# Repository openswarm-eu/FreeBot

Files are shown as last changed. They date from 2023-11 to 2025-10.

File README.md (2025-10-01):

# FreeBot
Contains FreeBot files and source code.
The Hardware folder contains schematics for the various versions of the FreeBot board and associated evaluation boards.
The software folder contains the FreeBot subfolder, which contains the core functionality of FreeBot and reference implementation of the library for BLE control. 
The repository will keep being updated with designs for both hardware and software.

# Hardware revisions

| Version | SoC | Feather-header | Picture |
|:---:|:---:|:---:|:---:|
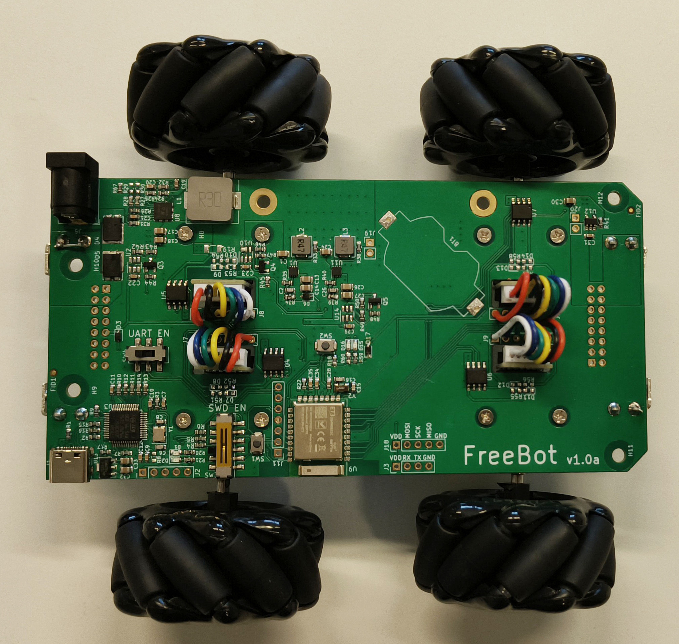
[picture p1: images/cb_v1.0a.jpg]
Picture of CapBot v1.0a
| [v1.0a](#v10a) | nrf52840 | &cross; ||
| [v1.1a](#v11a) | nrf52840 | &cross; |Picture of CapBot v1.1a|
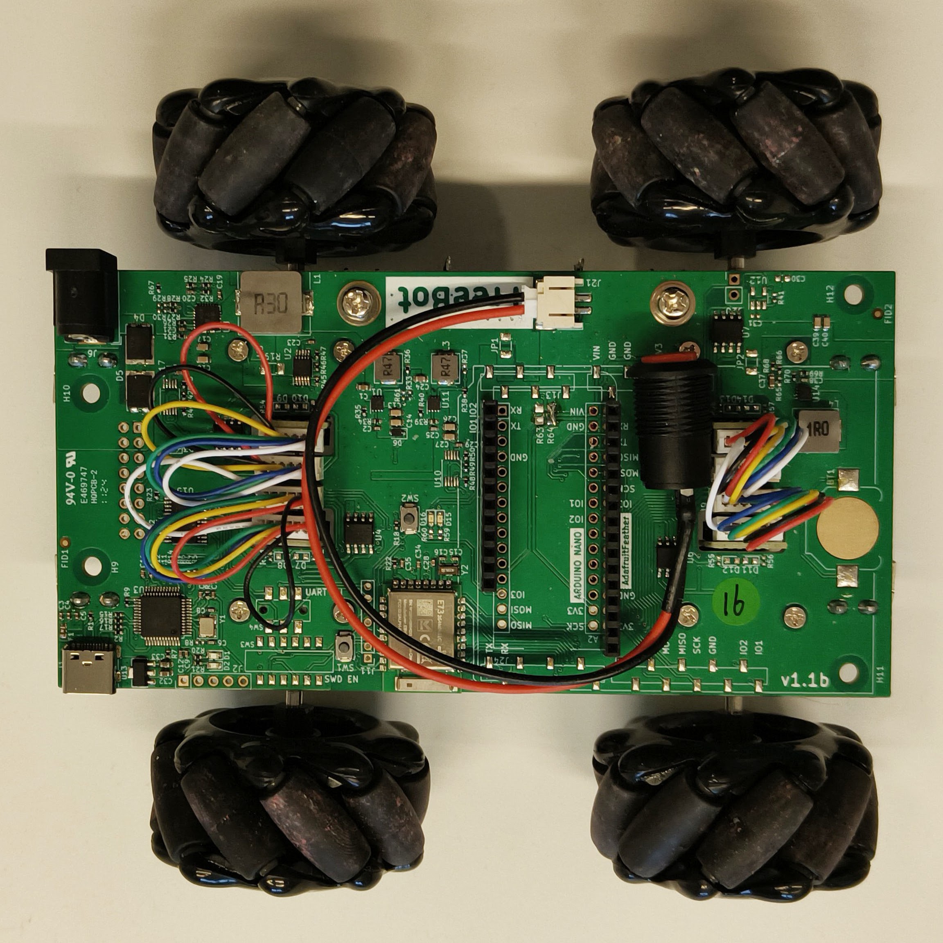
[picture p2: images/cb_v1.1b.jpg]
Picture of CapBot v1.1b
| [v1.1b](#v11b) | nrf52840 | &check; ||

## v1.0a

CapBot v1.0 has a physical switch (`SW4`) to cut the UART lines from the DAP-link on-board debugger.
This switch should be enabled when printing to a serial terminal over USB.

Furthermore, another physical switch (`SW3`) cuts the SWD lines used for programming the &micro;Processor.
This switch should be enabled in order to flash.

## v1.1a

Nothing special (yet).

## v1.1b

> [!WARNING]
> The pins `IO1`, `IO2` and `IO3` on the feather-header correspond with `D15`, `D16` and `SW2` respectively.
> Make sure that these are not shorted accidentally because of this.
> Schematic view

# Acknowledgement

Part of the source code in this repository is developed within the frame and for the purpose of the OpenSwarm project. This project has received funding from the European Unioan's Horizon Europe Framework Programme under Grant Agreement No. 101093046.

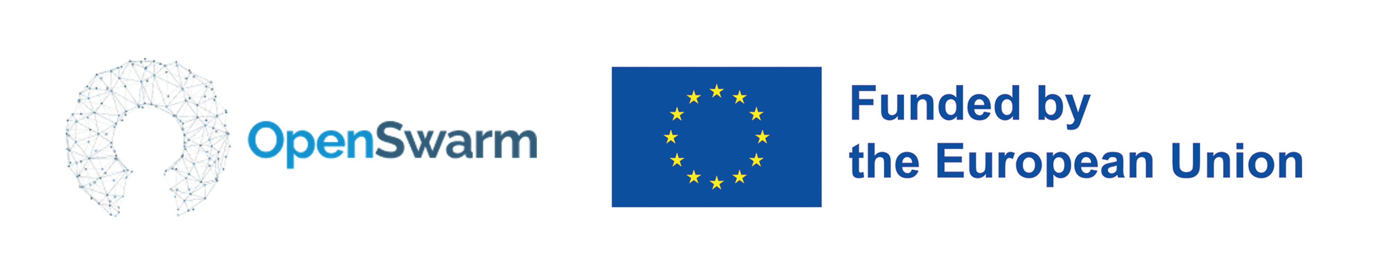
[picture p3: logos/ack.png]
OpenSwarm - Funded by the European Union


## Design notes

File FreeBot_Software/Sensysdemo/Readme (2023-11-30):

This version is based on the Adafruit nrf52840 express, and the code can be opened and used with an Arduino.

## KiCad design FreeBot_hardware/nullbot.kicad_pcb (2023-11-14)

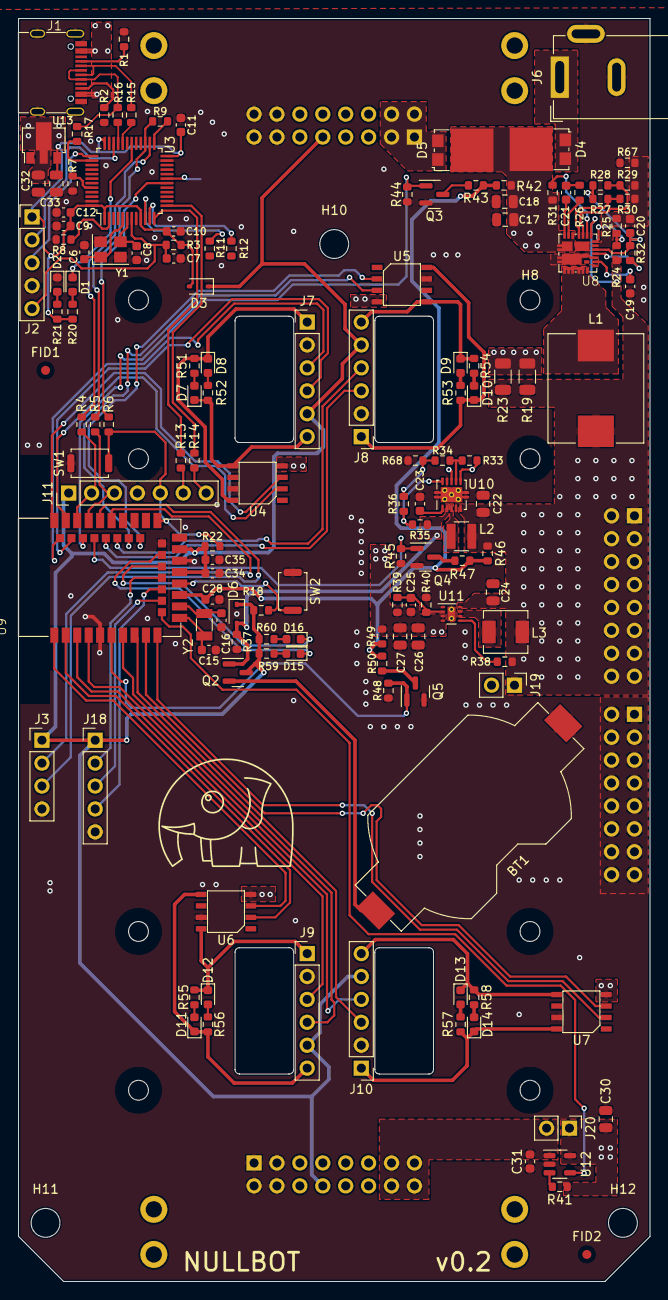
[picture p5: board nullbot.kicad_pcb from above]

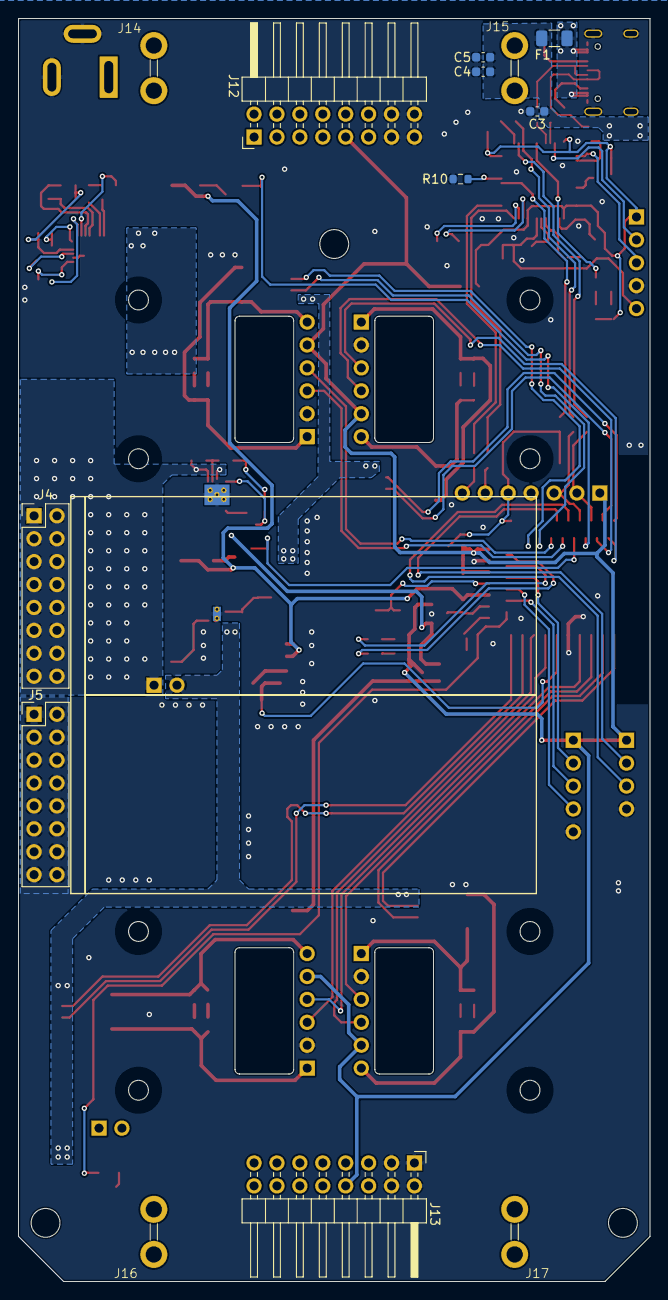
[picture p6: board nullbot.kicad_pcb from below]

Board: 2 copper layers, 70.0 x 140.0 mm, 165 parts (13 on the bottom side), 116 nets.

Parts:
BT1: Battery_Cell; BatteryHolder_Keystone_1058_1x2032
C3, C4, C5, C20: 1uF; C_0603_1608Metric
C6, C8: 22p; C_0603_1608Metric
C7, C9, C10, C11, C12: 100n; C_0603_1608Metric
C15, C16: 12pF; C_0603_1608Metric
C17, C18, C26, C27: 22uF; C_0805_2012Metric
C19: 2.2uF; C_0603_1608Metric
C21, C23, C31, C34, C35: 0.1uF; C_0603_1608Metric
C22, C24, C30, C32, C33: 10uF; C_0805_2012Metric
C25: 10pF; C_0603_1608Metric
C28: 0.01uF; C_0603_1608Metric
D1: Red; LED_0603_1608Metric
D2: Green; LED_0603_1608Metric
D3, D6: CUS10S30,H3F; D_SOD-323
D4, D5: 10S45SP; TO-277A
D7, D10, D11, D14: GREEN LED NCD0603G1; LED_0603_1608Metric
D8, D9, D12, D13: RED LED NCD0603R1; LED_0603_1608Metric
D15, D16: 19-217/BHC-ZL1M2RY/3T; LED_0603_1608Metric
F1: S1206-F-6.0A; Fuse_1206_3216Metric
FID1, FID2: Fiducial; Fiducial_1mm_Mask2mm
H1, H2, H3, H4, H5, H6, H7, H8: MountingHole; MountingHole_2.2mm_M2_ISO7380
H10, H11, H12: MountingHole; MountingHole_3.2mm_M3_ISO14580
J1: USB-type-c-16p; TYPE-C-31-M-12
J2, J18: Conn_01x05; PinHeader_1x05_P2.54mm_Vertical
J3: Conn_01x04; PinHeader_1x04_P2.54mm_Vertical
J4, J5: Conn_02x08_Counter_Clockwise; PinHeader_2x08_P2.54mm_Vertical
J6: Barrel_Jack_MountingPin; BarrelJack_GCT_DCJ200-10-A_Horizontal
J7, J8, J9, J10: Conn_01x06; PinHeader_1x06_P2.54mm_Vertical
J11: Conn_01x07; PinHeader_1x07_P2.54mm_Vertical
J12, J13: Conn_02x08_Odd_Even; PinHeader_2x08_P2.54mm_Horizontal
J14, J17: Conn_01x01; M3-side-terminal-DZ-32
J15, J16: Conn_01x01; M3-side-terminal-DZ-43
J19, J20: Conn_01x02; PinHeader_1x02_P2.54mm_Vertical
L1: 300nH; L_Chilisin_BMRF00101040
L2: 2.2uH SWPA3015S2R2MT; L_Abracon_ASPI-3012S
L3: 470nH FXL0420-R47-M; L_Sunlord_MWSA0412S
Q2: SSM3J332R; SOT-23
Q3, Q4, Q5: 2N7002; SOT-23
R1, R2: 5.1k; R_0603_1608Metric
R3, R7, R18, R22, R27, R31, R32, R38, R40, R41, R44, R45, R48: 100k; R_0603_1608Metric
R4, R5, R6, R11, R12, R13, R14, R15, R16: 22; R_0603_1608Metric
R8: 10k DNP; R_0603_1608Metric
R9, R20, R52, R53, R56, R57, R59, R60: 100; R_0603_1608Metric
R10, R68: 0; R_0603_1608Metric
R17: 1.5k; R_0603_1608Metric
R19, R23: DNP; R_1206_3216Metric
R21, R51, R54, R55, R58: 27; R_0603_1608Metric
R24: 36.5k; R_0603_1608Metric
R25, R34, R43, R47, R50: 10k; R_0603_1608Metric
R26, R67: 1; R_0603_1608Metric
R28: 499k; R_0603_1608Metric
R29, R30: DNP; R_0603_1608Metric
R33: 34.8k; R_0603_1608Metric
R35, R37: 1M; R_0603_1608Metric
R36: 180k; R_0603_1608Metric
R39: 316k; R_0603_1608Metric
R42, R46, R49: 390k; R_0603_1608Metric
SW1, SW2: TS-1088-AR02016; SW_Push_SPST_NO_Alps_SKRK
U3: STM32F103CBTx; LQFP-48_7x7mm_P0.5mm
U4, U5, U6, U7: BDR6120H; motor-driver-BDR6120H
U8: SIC431AED-T1-GE3; MLP44-24L SiC431
U9: E73-2G4M08S1C
U10: TPS61201DRC; Texas_S-PVSON-N10_ThermalVias
U11: WSON-8-1EP_2x2mm_P0.5mm_EP0.9x1.6mm_ThermalVias
U12: RT9742AGJ5F; TSOT-23-5
U13: HT7533-1; SOT-89-3
Y1: Crystal_GND24; Crystal_SMD_3225-4Pin_3.2x2.5mm
Y2: Q13FC1350000400; Crystal_SMD_3215-2Pin_3.2x1.5mm

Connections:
/USB-VDD: C9.1, C10.1, C11.1, C12.1, C33.1, D3.2 (A), J2.1, R3.2, R20.1, R21.1, U3.1 (VBAT), U3.9 (VDDA), U3.24 (VDD), U3.36 (VDD), U3.48 (VDD), U13.3 (VOUT)
/Vbotin: D5.1 (A), D5.2 (A), J12.1, J12.2, J12.3, J12.4
/Vbotout: C31.2, J13.13, J13.14, J13.15, J13.16, J20.2, U12.1 (VOUT)
/Vmotor: C25.2, C26.1, C27.1, C30.1, J19.2, J20.1, R39.1, R41.1, R49.1, U4.4 (VDD), U5.4 (VDD), U6.4 (VDD), U7.4 (VDD), U11.3 (VOUT), U11.4 (VOUT), U12.5 (VIN)
/daplink/dap-inner-usb_N: R15.2, U3.32 (PA11)
/daplink/dap-inner-usb_P: R16.2, U3.33 (PA12)
/daplink/dap-led-red: D1.1 (K), U3.30 (PA9)
/daplink/dap-nrst: C7.1, J2.5, R3.1, U3.7 (NRST)
/daplink/dap-swclk: J2.3, U3.37 (PA14)
/daplink/dap-swdio: J2.2, U3.34 (PA13)
/daplink/dap-usbd_N: J1.A7 (DN1), J1.B7 (DN2), R15.1
/daplink/dap-usbd_P: J1.A6 (DP1), J1.B6 (DP2), R16.1, R17.2
/daplink/tgt-swd.clk: J11.2, R4.1, U9.39 (SWDCLK)
/daplink/tgt-swd.io: J11.3, R5.1, U9.37 (SWDIO)
/daplink/tgt-swd.rst: J11.5, R6.1, R22.2, SW1.2, U9.26 (P0.18/RESET)
/daplink/tgt-uart.rx: J11.7, R14.2
/daplink/tgt-uart.tx: J11.6, R13.2
/mcu/V-mea: C28.1, R42.2, R43.1, R46.2, R47.1, R49.2, R50.1, U9.15 (P0.05/AIN3)
/mcu/Vbotout-EN: U9.12 (P0.26), U12.4 (EN)
/mcu/Vcap-mea-en: Q4.1 (G), R45.1, U9.36 (P1.00/SWO)
/mcu/Vin-mea-en: Q3.1 (G), R44.1, U9.38 (P1.02-LS)
/mcu/Vmotor-mea-en: Q5.1 (G), R48.1, U9.6 (P1.13-LS)
/mcu/m1-ctrl.in-a: U4.2 (INA), U9.41 (P0.09/NFC1-LS)
/mcu/m1-ctrl.in-b: U4.3 (INB), U9.43 (P0.10/NFC2-LS)
/mcu/m1-hall.c1: J7.4, U9.40 (P1.04-LS)
/mcu/m1-hall.c2: J7.3, U9.42 (P1.06-LS)
/mcu/m2-ctrl.in-a: U5.2 (INA), U9.28 (P0.15)
/mcu/m2-ctrl.in-b: U5.3 (INB), U9.30 (P0.17)
/mcu/m2-hall.c1: J8.4, U9.32 (P0.20)
/mcu/m2-hall.c2: J8.3, U9.34 (P0.22)
/mcu/m3-ctrl.in-a: U6.2 (INA), U9.2 (P1.10-LS)
/mcu/m3-ctrl.in-b: U6.3 (INB), U9.1 (P1.11-LS)
/mcu/m3-hall.c1: J9.4, U9.7 (P0.02/AIN1-LS)
/mcu/m3-hall.c2: J9.3, U9.3 (P0.03/AIN1-LS)
/mcu/m4-ctrl.in-a: U7.2 (INA), U9.10 (P0.30/AIN6-LS)
/mcu/m4-ctrl.in-b: U7.3 (INB), U9.9 (P0.31/AIN7-LS)
/mcu/m4-hall.c1: J10.4, U9.4 (P0.28/AIN4-LS)
/mcu/m4-hall.c2: J10.3, U9.8 (P0.29/AIN5-LS)
/mcu/nrf-led1: D15.1 (K), U9.22 (P0.07)
/mcu/nrf-led2: D16.1 (K), U9.20 (P0.12)
/mcu/nrf-sw: R18.2, SW2.2, U9.17 (P1.09)
/mcu/peri-i2c.scl: J3.3, U9.35 (P0.24)
/mcu/peri-i2c.sda: J3.2, U9.33 (P0.13)
/mcu/peri-spi.miso: J18.4, U9.16 (P0.08)
/mcu/peri-spi.mosi: J18.2, U9.18 (P0.04/AIN2)
/mcu/peri-spi.sck: J18.3, U9.14 (P0.06)
/pwr1/Vcap: C22.1, C24.1, J4.1, J4.2, J4.3, J4.4, J4.5, J4.6, J4.7, J4.8, J4.9, J4.10, J4.11, J4.12, J4.13, J4.14, J4.15, J4.16, J19.1, L1.2, L2.1, L3.1, R19.2, R23.2, R24.1, R33.1, R38.1, R46.1, U8.18 (Vout), U10.5 (VIN), U10.6 (EN), U10.8 (PS), U11.8 (VIN)
/pwr1/buck_en: R31.2, U8.19 (EN)
/pwr2/Vbotout-overcurr: R41.2, U12.3 (~FLG)
/pwr2/Vcap_reg: D6.2 (A), Q2.1 (G), R35.1, R37.1, U10.2 (VOUT)
/pwr2/Vmotor-EN: R38.2, U11.5 (EN)
GND: BT1.2 (-), C3.2, C4.2, C5.2, C6.2, C7.2, C8.2, C9.2, C10.2, C11.2, C12.2, C15.2, C16.2, C17.2, C18.2, C19.2, C20.2, C22.2, C23.1, C24.2, C26.2, C27.2, C28.2, C30.2, C31.1, C32.2, C33.2, C34.2, C35.2, D2.1 (K), J1.0 (SH), J1.1 (SH), J1.2 (SH), J1.3 (SH), J1.A1 (GND), J1.A12 (GND), J1.B1 (GND), J1.B12 (GND), J2.4, J3.4, J5.1, J5.2, J5.3, J5.4, J5.5, J5.6, J5.7, J5.8, J5.9, J5.10, J5.11, J5.12, J5.13, J5.14, J5.15, J5.16, J6.2, J6.3 (MP), J7.2, J8.2, J9.2, J10.2, J11.4, J12.13, J12.14, J12.15, J12.16, J13.1, J13.2, J13.3, J13.4, J18.5, Q3.2 (S), Q4.2 (S), Q5.2 (S), R1.2, R2.2, R7.2, R8.1, R10.1, R25.2, R29.2, R30.2, R37.2, R40.2, R44.2, R45.2, R48.2, R67.1, R67.2, R68.2, SW1.1, SW2.1, U3.8 (VSSA), U3.23 (VSS), U3.35 (VSS), U3.47 (VSS), U4.7 (GND), U5.7 (GND), U6.7 (GND), U7.7 (GND), U8.3 (Pgnd), U8.4 (Pgnd), U8.13 (Pgnd), U8.16 (Agnd), U8.25 (Agnd), U8.27 (Pgnd), U9.5 (GND), U9.21 (GND), U9.24 (GND), U10.4 (PGND), U10.9 (GND), U10.11 (PAD), U11.1 (AGND), U11.9 (PGND), U12.2 (GND), U13.1 (GND), Y1.2, Y1.4
unnamed: BT1.1 (+), Q2.2 (S)
unnamed: C21.2, R26.2
unnamed: D1.2 (A), R20.2
unnamed: D2.2 (A), R21.2
unnamed: D4.1 (A), D4.2 (A), J6.1
unnamed: C17.1, C18.1, D4.3 (K), D5.3 (K), R19.1, R23.1, R31.1, R42.1, U8.1 (Vin), U8.2 (Vin), U8.22 (Vin), U8.26 (Vin)
unnamed: D7.2 (A), R51.2
unnamed: D7.1 (K), J7.6, R52.2, U4.5 (OUTB)
unnamed: D8.2 (A), R52.1
unnamed: D8.1 (K), J7.1, R51.1, U4.8 (OUTA)
unnamed: D9.2 (A), R53.2
unnamed: D9.1 (K), J8.6, R54.2, U5.5 (OUTB)
unnamed: D10.2 (A), R54.1
unnamed: D10.1 (K), J8.1, R53.1, U5.8 (OUTA)
unnamed: D11.2 (A), R55.2
unnamed: D11.1 (K), J9.6, R56.2, U6.5 (OUTB)
unnamed: D12.2 (A), R56.1
unnamed: D12.1 (K), J9.1, R55.1, U6.8 (OUTA)
unnamed: D13.2 (A), R57.2
unnamed: D13.1 (K), J10.6, R58.2, U7.5 (OUTB)
unnamed: D14.2 (A), R58.1
unnamed: D14.1 (K), J10.1, R57.1, U7.8 (OUTA)
unnamed: D15.2 (A), R59.2
unnamed: D16.2 (A), R60.2
unnamed: F1.1, J1.A4 (VBUS), J1.A9 (VBUS), J1.B4 (VBUS), J1.B9 (VBUS)
unnamed: J1.A5 (CC1), R1.1
unnamed: J1.B5 (CC2), R2.1
unnamed: L1.1, U8.5 (SW), U8.6 (SW), U8.7 (SW), U8.8 (SW), U8.9 (SW)
unnamed: L3.2, U11.6 (SW), U11.7 (SW)
unnamed: Q3.3 (D), R43.2
unnamed: Q4.3 (D), R47.2
unnamed: Q5.3 (D), R50.2
unnamed: R34.2, R36.2, R68.1
unnamed: R7.1, U3.44 (BOOT0)
unnamed: R11.1, U3.10 (PA0)
unnamed: R12.1, U3.11 (PA1)
unnamed: R13.1, U3.12 (PA2)
unnamed: R14.1, U3.13 (PA3)
unnamed: R17.1, U3.38 (PA15)
unnamed: R6.2, U3.18 (PB0)
unnamed: R10.2, U3.19 (PB1)
unnamed: R9.2, U3.25 (PB12)
unnamed: R4.2, U3.26 (PB13)
unnamed: R5.2, R9.1, U3.27 (PB14)
unnamed: R8.2, U3.2 (PC13)
unnamed: C6.1, U3.5 (PD0), Y1.1
unnamed: C8.1, U3.6 (PD1), Y1.3
unnamed: R26.1, U8.23 (BOOT)
unnamed: R24.2, R25.1, U8.17 (FB)
unnamed: R27.2, R30.1, U8.21 (MODE1)
unnamed: R28.2, R29.1, U8.20 (MODE2)
unnamed: C21.1, U8.24 (PHASE)
unnamed: R32.2, U8.14 (Pgood)
unnamed: C20.1, R27.1, R28.1, R32.1, U8.15 (Vdd)
unnamed: C19.1, U8.12 (Vdrv)
unnamed: C15.1, U9.11 (P0.00/XL1), Y2.1
unnamed: C16.1, U9.13 (P0.01/XL2), Y2.2
unnamed: R35.2, R36.1, U10.10 (FB)
unnamed: L2.2, U10.3 (L)
unnamed: R33.2, R34.1, U10.7 (UVLO)
unnamed: C23.2, U10.1 (VAUX)
unnamed: C25.1, R39.2, R40.1, U11.2 (FB)
VBUS: C3.1, C4.1, C5.1, C32.1, F1.2, U13.2 (VIN)
VDD: C34.1, C35.1, D3.1 (K), D6.1 (K), J3.1, J7.5, J8.5, J9.5, J10.5, J11.1, J12.9, J13.8, J18.1, Q2.3 (D), R18.1, R22.1, R59.1, R60.1, U9.19 (VDD), U9.23 (VDDH)
